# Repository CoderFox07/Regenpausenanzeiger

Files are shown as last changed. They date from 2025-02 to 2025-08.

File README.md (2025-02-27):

# Regenpausenanzeiger – Die etwas andere Wetterstation 🌦️

Der Regenpausenanzeiger ist ein modulares System zur Erfassung, Verarbeitung und Visualisierung von Wetterdaten. Drei vernetzte Stationen arbeiten dabei zusammen: Eine solarbetriebene Messstation auf dem Dach erfasst Temperatur, Luftfeuchtigkeit und Niederschlag. Eine Kontrollstation im Sekretariat verarbeitet die Daten und eine Anzeigestation macht die Wetterdaten für alle Schüler und Lehrkräfte zugänglich.

An vielen Schulen müssen die Schüler die Pausen grundsätzlich im Freien verbringen. Bei Regen oder sehr niedrigen Temperaturen dürfen sie jedoch im Gebäude bleiben. Dies ist dann eine Regen- oder Kältepause. Oft ist die Einschätzung der Wetterlage nicht ganz eindeutig oder die Durchsage, dass die Pause drinnen verbracht werden darf, wird vergessen.

Der Regenpausenanzeiger automatisiert diese Entscheidung – ist aber weit mehr als nur ein Pausenhelfer. Die erfassten Wetterdaten lassen sich vielfältig nutzen, etwa für den Unterricht oder als langfristige Wetterbeobachtungen. Er lässt sich ebenfalls leicht als Wetterstation für zu Hause umfunktionieren.

In diesem Repository befinden sich die Programme für die Stationen, 3D-Modelle und eine detaillierte Anleitung zur Einrichtung der Anzeigestation.

YouTube-Video für weitere spannende Details: [Video Regenpausenanzeiger](https://youtu.be/XeapUQ0t9Z4)

Ein ausführlicher Artikel zum Regenpausenanzeiger wurde von mir im AATiS-Praxisheft veröffentlicht: AATiS-Praxisheft 35 (2025), S. 36.
Homepage zum AATiS e.V., auf der man das Heft bestellen kann: [AATiS e.V.](https://www.aatis.de/)

Hier sind Links zu einigen der benötigten Komponenten:

-   **Solarpanel (5W):** [Waveshare Solarpanel 5 W](https://www.reichelt.de/de/de/shop/produkt/entwicklerboards_-_solarpanel_5_w-266039) (Reichelt)
-   **Solar Laderegler:** [Waveshare Solar Power Manager](https://www.reichelt.de/de/de/shop/produkt/entwicklerboards_-_solar_ladegeraet_fuer_6_bis_24_v_panels-266038) (Reichelt)
-   **Li-Ion Akku (14500, 750mAh):** [14500 Li-Ion-Akku 750 mAh mit Schutzschaltung](https://www.reichelt.de/de/de/shop/produkt/led_lenser_li-ion_14500_750_mah_mit_schutzschaltung-302260) (Reichelt)
-   **Trichter (20cm Durchmesser):** [Trichter 20cm Durchmesser](https://www.amazon.de/dp/B000VD6UXC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) (Amazon)

**Haftungsausschluss:**

Der Nachbau und die Verwendung dieses Projekts erfolgen auf eigene Gefahr. Der Autor übernimmt keine Haftung für Schäden, die durch den Nachbau oder die Verwendung entstehen.

**Disclaimer:**

The construction and use of this project are at your own risk. The author assumes no liability for any damage caused by the construction or use.

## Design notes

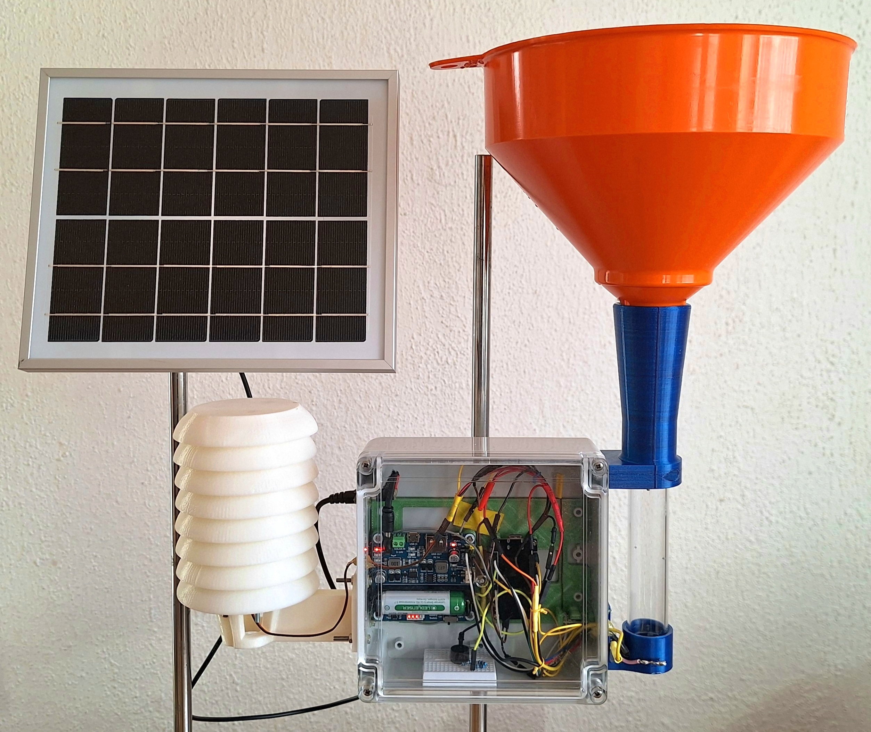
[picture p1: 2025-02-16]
Bilder/Dachstation.jpg

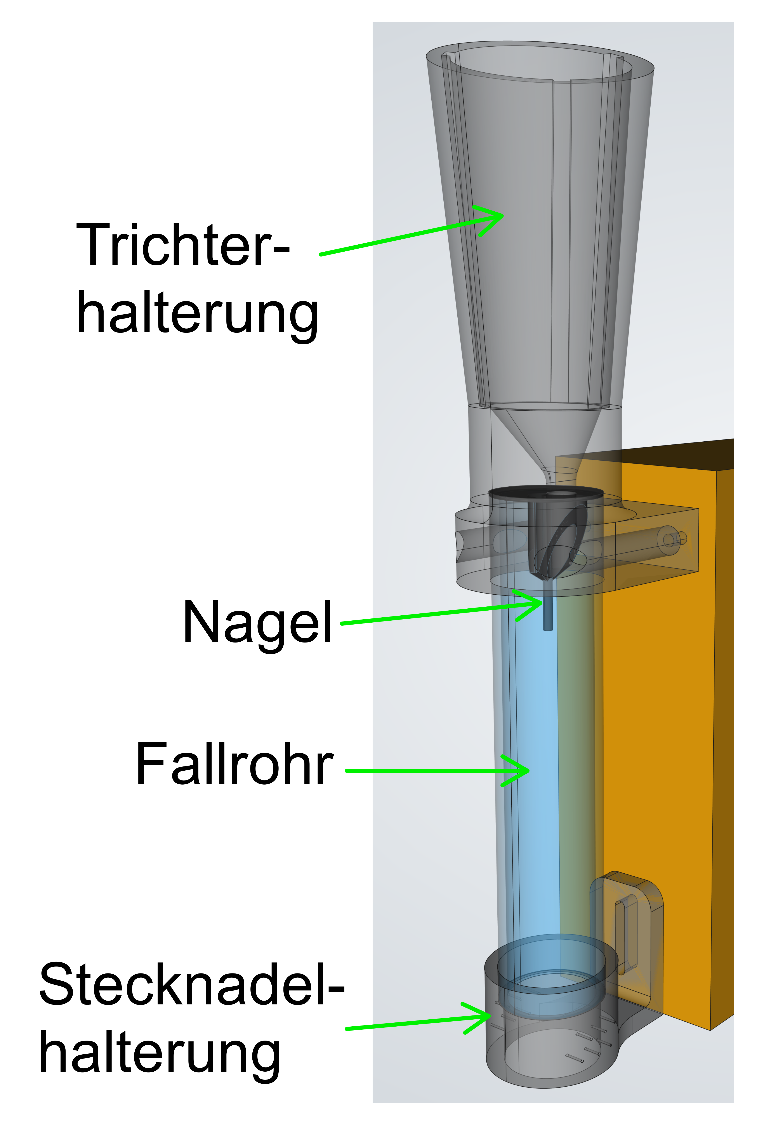
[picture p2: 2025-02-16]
Bilder/Beschriftungen Regensensor.png

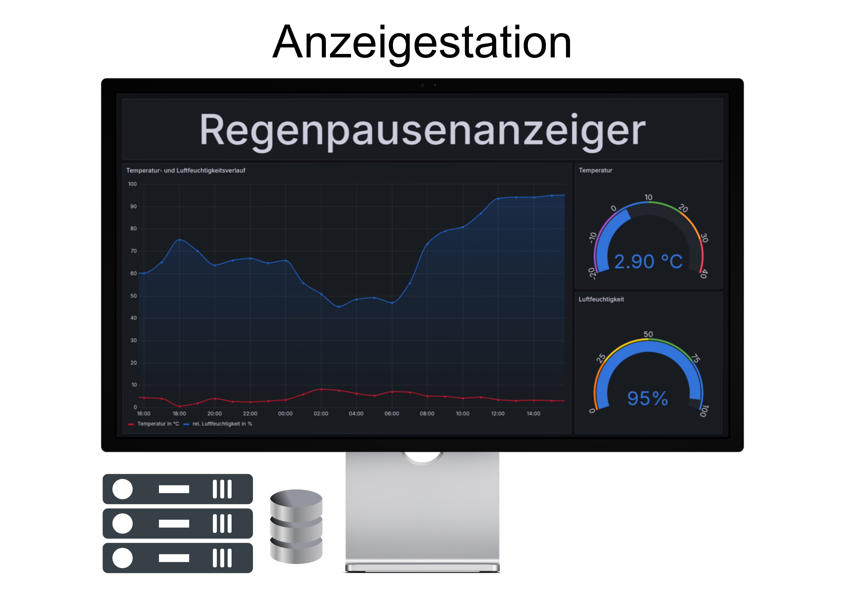
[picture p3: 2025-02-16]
Bilder/Anzeigestation.png

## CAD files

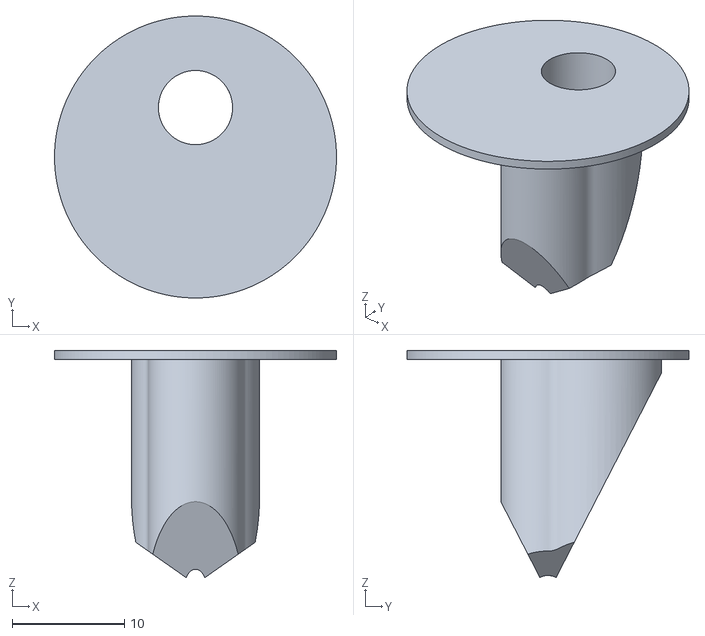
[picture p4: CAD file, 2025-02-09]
3D-Modelle/Regensensor/Regensensor V2-Wasserableiter.stl
25.1 x 25.1 x 20.2

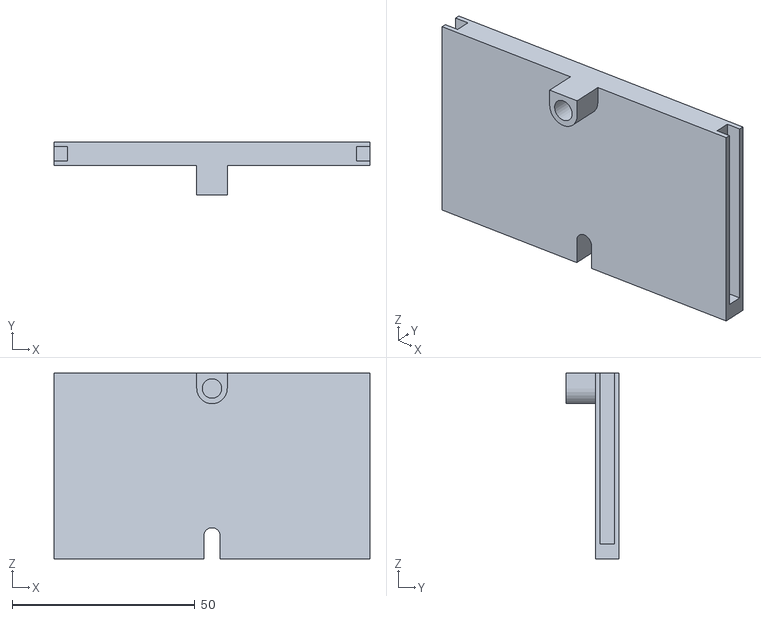
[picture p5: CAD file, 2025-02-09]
3D-Modelle/Sekretariatsstation/Sekretariatsstation-Einschiebedeckel.stl
86.5 x 14.6 x 50.8

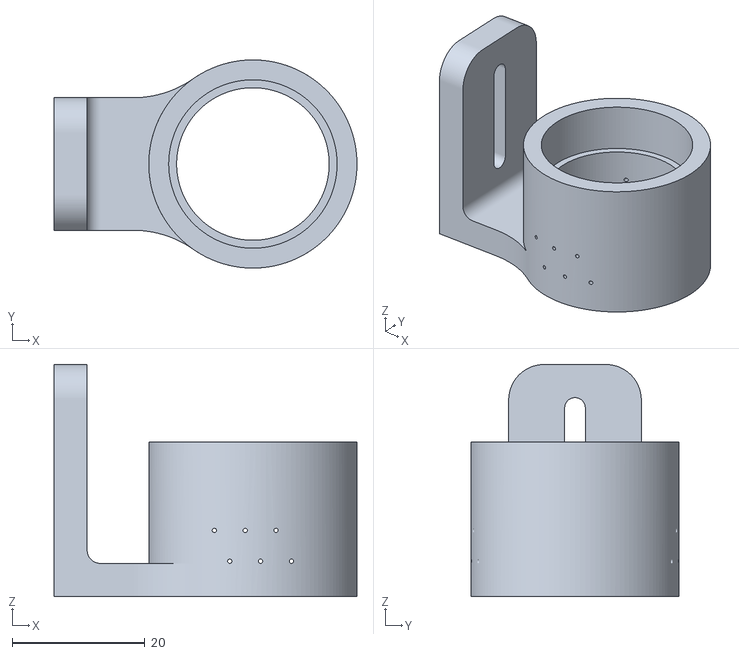
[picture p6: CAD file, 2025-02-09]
3D-Modelle/Regensensor/Regensensor V2-Stecknadelhalterung.stl
45.7 x 31.4 x 35.0

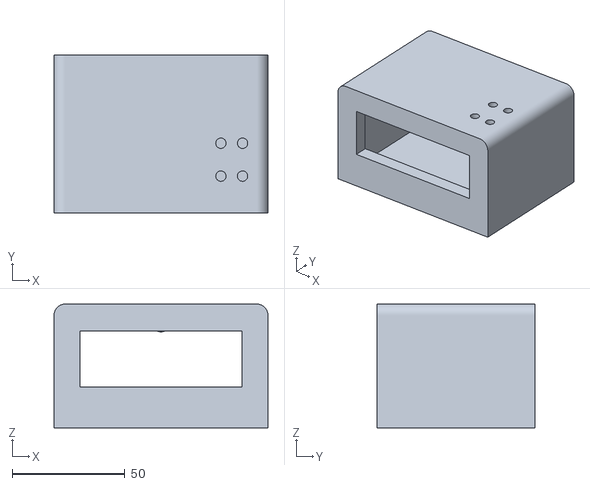
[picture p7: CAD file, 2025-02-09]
3D-Modelle/Sekretariatsstation/Sekretariatsstation-Box.stl
95.0 x 70.0 x 55.0

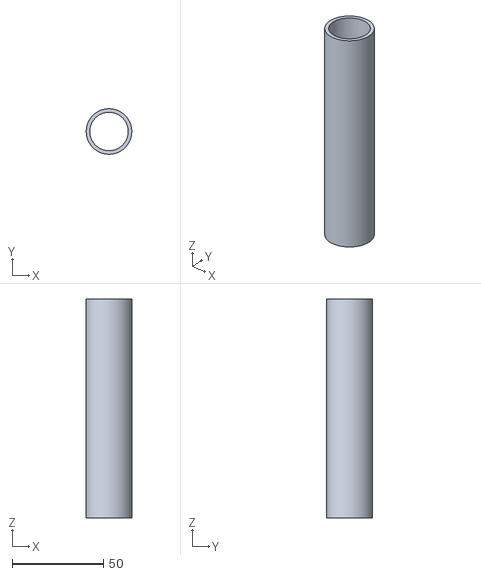
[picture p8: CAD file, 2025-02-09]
3D-Modelle/Regensensor/Regensensor V2-Rohr.stl
25.0 x 25.0 x 120.0

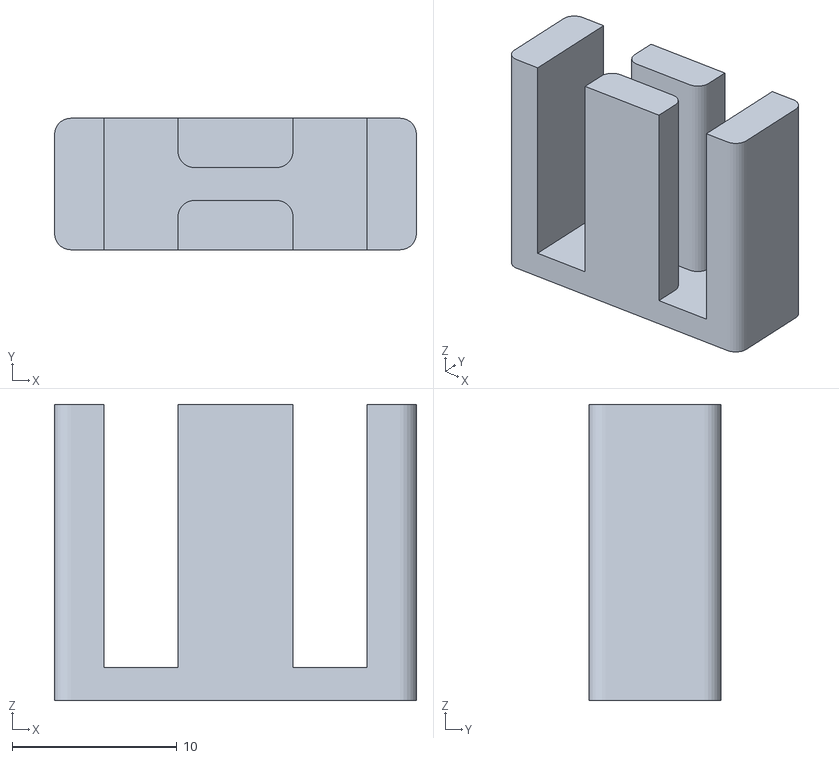
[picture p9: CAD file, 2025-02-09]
3D-Modelle/Sekretariatsstation/Sekretariatsstation-LoRa-Halterung.stl
22.0 x 8.00 x 18.0

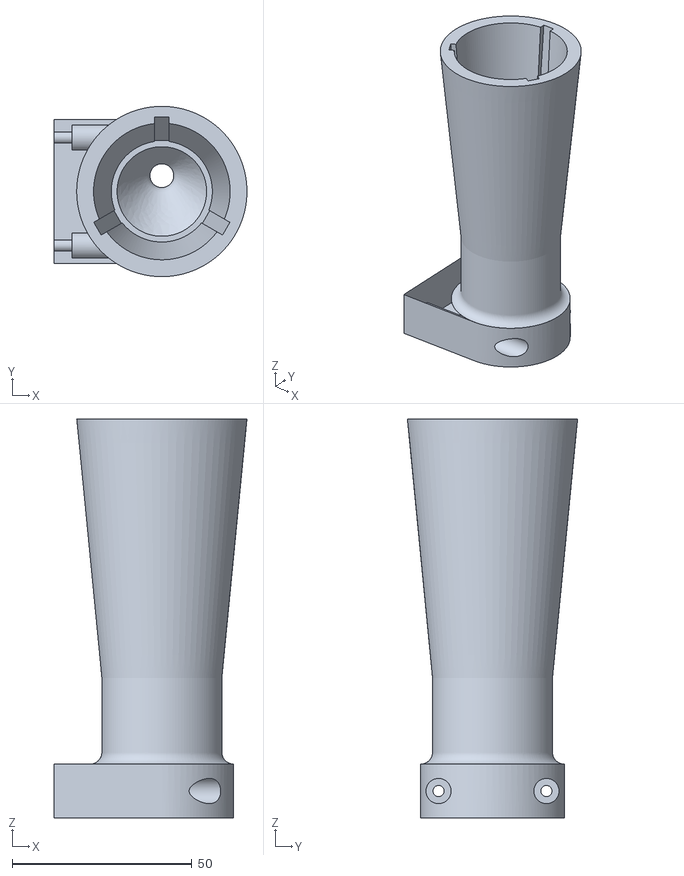
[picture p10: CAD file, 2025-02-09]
3D-Modelle/Regensensor/Regensensor V2-Trichterhalterung.stl
53.7 x 47.4 x 111.0

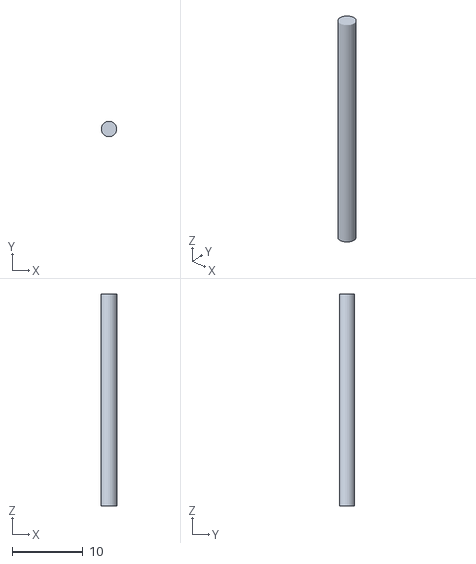
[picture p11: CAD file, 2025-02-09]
3D-Modelle/Regensensor/Regensensor V2-Nagel.stl
2.20 x 2.18 x 30.0

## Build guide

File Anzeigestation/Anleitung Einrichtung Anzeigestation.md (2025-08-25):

# Einrichtung der Anzeigestation des Regenpausenanzeigers

Diese Anleitung beschreibt die Installation und Konfiguration der Anzeigestation des Regenpausenanzeigers. Sie umfasst die Einrichtung eines LAMP-Servers (Linux, Apache, MariaDB, PHP), die Installation von phpMyAdmin und Grafana, sowie die Konfiguration für den automatischen Start und die Anzeige der Wetterdaten.
Dazu wird ein Computer mit Debian als Betriebssystem mit XFCE als Oberfläche vorrausgesetzt.

**Hinweis**: Diese Anleitung wurde mit Debian 12 und XFCE 4.18 getestet und sollte auch mit zukünftigen Debian-Versionen kompatibel sein. Bei einem Systemupgrade auf eine neue Debian-Hauptversion wird empfohlen, externe Paketquellen wie die von Grafana vorübergehend zu deaktivieren. Dabei muss Grafana nicht deinstalliert werden und Konfigurationen der Dashboards bleiben erhalten. Nach dem Upgrade müssen die Quellen wieder aktiviert werden, woraufhin Grafana über den Paketmanager normal aktualisiert werden kann.

## 1. Installation der Basispakete

Nach dem ersten Start des Systems installiere die folgenden Pakete:

```bash
sudo apt install htop net-tools
```

## 2. Optionale Zwei-Faktor-Authentifizierung (2FA) einrichten

Für Benutzer kann zusätzlich eine 2FA für erhöhte Sicherheit eingerichtet werden.
Dazu muss folgendes Paket installiert werden: libpam-google-authenticator
```bash
sudo apt install libpam-google-authenticator
```

Danach als normaler Benutzer einrichten:
```bash
google-authenticator
```
Anschließend müssen weitere Einstellungen vorgenommen werden.
Öffne dazu die Datei `/etc/pam.d/common-auth`:
```bash
sudo nano /etc/pam.d/common-auth
```
Sie sollte wie folgt angepasst werden:
```
#
# /etc/pam.d/common-auth - authentication settings common to all services
#
# This file is included from other service-specific PAM config files,
# and should contain a list of the authentication modules that define
# the central authentication scheme for use on the system
# (e.g., /etc/shadow, LDAP, Kerberos, etc.).  The default is to use the
# traditional Unix authentication mechanisms.
#
# As of pam 1.0.1-6, this file is managed by pam-auth-update by default.
# To take advantage of this, it is recommended that you configure any
# local modules either before or after the default block, and use
# pam-auth-update to manage selection of other modules.  See
# pam-auth-update(8) for details.

# here are the per-package modules (the "Primary" block)
# Hinweis: forward_pass sorgt dafür, dass man den Verification-Code direkt hinter das Passwort schreiben kann.
auth    required                        pam_google_authenticator.so forward_pass
auth	[success=1 default=ignore]	pam_unix.so nullok
# here's the fallback if no module succeeds
auth	requisite			pam_deny.so
# prime the stack with a positive return value if there isn't one already;
# this avoids us returning an error just because nothing sets a success code
# since the modules above will each just jump around
auth	required			pam_permit.so
# and here are more per-package modules (the "Additional" block)
# end of pam-auth-update config
```

## 3. VNC-Einrichtung

Installiere die notwendigen Pakete:
```bash
sudo apt install tigervnc-standalone-server tigervnc-common tigervnc-tools tigervnc-xorg-extension
```

### 3.1. VNC für neue Session

1.  **Anpassung des `xstartup`-Skripts:**
    Öffne die Datei `~/.vnc/xstartup`:
    ```bash
    nano ~/.vnc/xstartup
    ```

    Stelle sicher, dass der Inhalt wie folgt aussieht (ggf. anpassen):
    ```bash
    #!/bin/bash
    unset SESSION_MANAGER
    unset DBUS_SESSION_BUS_ADDRESS
    exec /usr/bin/startxfce4
    ```

    Mache das Skript ausführbar:
    ```bash
    chmod +x ~/.vnc/xstartup
    ```

2.  **VNC-Passwort festlegen (für den Benutzer, nicht root!):**
    ```bash
    vncpasswd
    ```

### 3.2 VNC für Shared Session (aktuellen Desktop teilen und fernsteuern)

1. Konfiguration:
Erstelle oder bearbeite die Datei /etc/X11/xorg.conf.d/10-tigervnc.conf:
```bash
sudo nano /etc/X11/xorg.conf.d/10-tigervnc.conf
```

Füge Folgendes ein:
```
Section "Module"
    Load "vnc"
EndSection

Section "Screen"
    Identifier "Screen0"
    Option "passwordFile" "/etc/vncpasswd"
    Option "localhost" "yes" #sorgt dafuer, dass es nicht von aussen erreichbar ist
EndSection
```

2. Systemweites VNC-Passwort setzen:
```bash
sudo vncpasswd /etc/vncpasswd
sudo chmod 600 /etc/vncpasswd
```

3. Neustart
```bash
sudo reboot
```

### 3.3 VNC-Zugriff auf Regenpausenanzeiger über SSH-Tunnel für verschlüsselte Übertragung

**Shared Session (Bildschirm teilen):**

1.  **SSH-Tunnel auf dem *lokalen* Rechner erstellen:**
    ```bash
    ssh -L 5900:localhost:5900 user@regenpausenanzeiger
    ```

2.  **Mit VNC-Viewer verbinden:**
    Verwende einen VNC-Viewer auf dem lokalen Rechner (z.B. TigerVNC Viewer) und verbinde dich mit `localhost:5900`.

**Neue Session:**

1.  **VNC-Server auf dem *Regenpausenanzeiger* starten:**
    Dazu muss man sich zunächst über ssh einloggen und den folgenden Befehl ausführen:
    ```bash
    tigervncserver :1 -geometry 1920x1080 -localhost -xstartup ~/.vnc/xstartup
    ```

2.  **SSH-Tunnel auf dem *lokalen* Rechner erstellen:**
    ```bash
    ssh -L 5901:localhost:5901 user@regenpausenanzeiger
    ```

3.  **Mit VNC-Viewer verbinden:**
    Verwende einen VNC-Viewer auf dem lokalen Rechner (z.B. TigerVNC Viewer) und verbinde dich mit `localhost:5901`.

## 4. LAMP-Server einrichten

### 4.1 MariaDB installieren

```bash
sudo apt install mariadb-server
```

### 4.2 MySQL/MariaDB absichern

Führe das Skript zur Absicherung aus:

```bash
sudo mysql_secure_installation
```

Beantworte die Fragen wie folgt (wähle sichere Passwörter!):

*   Enter current password for root (enter for none): **(Enter drücken, falls kein Passwort gesetzt)**
*   Switch to unix\_socket authentication \[Y/n] **Y**
*   Change the root password? \[Y/n] **Y**
*   Remove anonymous users? \[Y/n] **Y**
*   Disallow root login remotely? \[Y/n] **Y**
*   Remove test database and access to it? \[Y/n] **Y**
*   Reload privilege tables now? \[Y/n] **Y**

### 4.3 PHP und Erweiterungen installieren

```bash
sudo apt install php php-mysql libapache2-mod-php php-cli
```

### 4.4 Apache neu starten

```bash
sudo systemctl restart apache2
```

### 4.5 Datenbank und Benutzer erstellen

1.  **Mit der MariaDB-Konsole verbinden:**
    ```bash
    sudo mysql -u root -p
    ```

2.  **Datenbank erstellen:**
    ```sql
    CREATE DATABASE wetterdaten;
    ```

3.  **Hauptbenutzer erstellen und Rechte vergeben (ersetze 'sicheres_passwort'!):**
    ```sql
    CREATE USER 'wetteruser'@'localhost' IDENTIFIED BY 'sicheres_passwort';
    GRANT ALL PRIVILEGES ON wetterdaten.* TO 'wetteruser'@'localhost';
    FLUSH PRIVILEGES;
    ```

4.  **Benutzer für Grafana (nur Lesezugriff) erstellen (ersetze 'sicheresPasswort2'!):**
    ```sql
    CREATE USER 'grafanauser'@'localhost' IDENTIFIED BY 'sicheresPasswort2';
    GRANT SELECT ON wetterdaten.* TO 'grafanauser'@'localhost';
    FLUSH PRIVILEGES;
    EXIT;
    ```

### 4.6 Tabelle für Wetterdaten erstellen
```bash
sudo mysql -u wetteruser -p wetterdaten
```

### 4.7 phpMyAdmin installieren
```bash
sudo apt install phpmyadmin
```

Bearbeite die Datei /etc/phpmyadmin/apache.conf, um den Zugriff nur vom lokalen Server zu erlauben:
```bash
sudo nano /etc/phpmyadmin/apache.conf
```

Für mehr Sicherheit kann der Zugriff auf phpMyAdmin von außen beschränkt werden, indem man nur lokalen Zugriff gewährt. Um trotzdem noch von anderen Computern darauf zugreifen zu können, kann man sich über einen SSH-Tunnel sicher verbinden und den Port weiterleiten.

Füge dazu folgende Zeilen hinzu, um den Zugriff nur von localhost zu erlauben:
```
<IfModule mod_authz_core.c>
    # Restrict access to localhost
    Require local
</IfModule>
```

Die komplette Datei (etc/phpmyadmin/apache.conf) sollte folgendermaßen aussehen:
```
# phpMyAdmin default Apache configuration

Alias /phpmyadmin /usr/share/phpmyadmin

<Directory /usr/share/phpmyadmin>
    Options SymLinksIfOwnerMatch
    DirectoryIndex index.php

    # limit libapache2-mod-php to files and directories necessary by pma
    <IfModule mod_php7.c>
        php_admin_value upload_tmp_dir /var/lib/phpmyadmin/tmp
        php_admin_value open_basedir /usr/share/phpmyadmin/:/usr/share/doc/phpmyadmin/:/etc/phpmyadmin/:/var/lib/phpmyadmin/:/usr/share/php/:/usr/share/javascript/
    </IfModule>

    # PHP 8+
    <IfModule mod_php.c>
        php_admin_value upload_tmp_dir /var/lib/phpmyadmin/tmp
        php_admin_value open_basedir /usr/share/phpmyadmin/:/usr/share/doc/phpmyadmin/:/etc/phpmyadmin/:/var/lib/phpmyadmin/:/usr/share/php/:/usr/share/javascript/
    </IfModule>

    # Zugriff auf localhost beschraenken:
    <IfModule mod_authz_core.c>
        # Restrict access to localhost
        Require local
    </IfModule>
</Directory>

# Disallow web access to directories that don't need it
<Directory /usr/share/phpmyadmin/templates>
    Require all denied
</Directory>
<Directory /usr/share/phpmyadmin/libraries>
    Require all denied
</Directory>
```

Anschließend muss Apache neu gestartet werden, sodass die Änderungen wirksam werden:
```bash
sudo systemctl restart apache2
```
Jetzt ist phpMyAdmin nicht mehr von außen erreichbar. Man kann entweder mit <http://localhost:8888/phpmyadmin/index.php> im Browserfenster vom Regenpausenanzeiger auf phpMyAdmin zugreifen oder mit einem SSH-Tunnel, indem man folgendes an einem anderen Rechner lokalen Rechner eingibt:

```bash
ssh -L 8888:localhost:80 user@regenpausenanzeiger
```

Dann kann man am lokalen Rechner folgendes im Browser eingeben, um auf phpMyAdmin zuzugreifen:
```
http://localhost:8888/phpmyadmin
```

Anschließend kann man mit phpMyAdmin die SQL-Datenbank genauer konfigurieren, wie im Bild gezeigt:
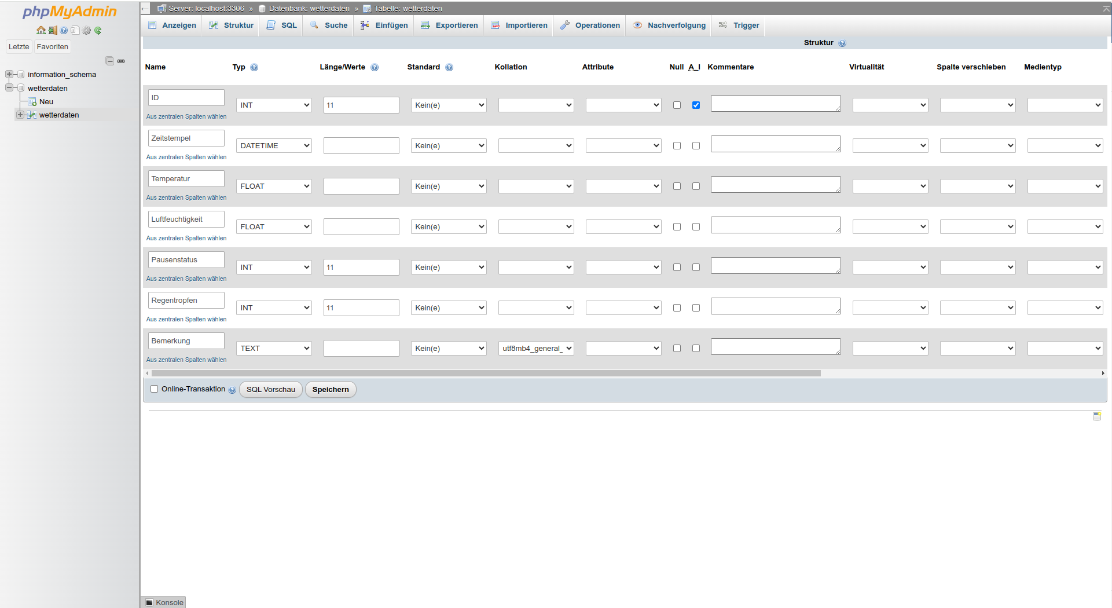
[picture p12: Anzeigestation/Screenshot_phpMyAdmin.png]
Screenshot Einrichtung SQL-Datenbank mit phpMyAdmin


Es werden insgesamt sieben Spalten benötigt:
1.  **ID:**
    Eine ID, die automatisch hochgezählt wird

2.  **Zeitstempel:**
    Für die Speicherung der Zeit: Wann die Wetterdaten von der Dachstation erfasst wurden.

3.  **Temperatur**

4.  **Luftfeuchtigkeit**

5.  **Pausenstatus:**
    Der Pausenstatus wird jedes Mal von der Sekretariatsstation mit übermittelt. Damit kann dann im Grafana-Dashboard entschieden werden, welcher Pausenmodus angezeigt werden soll. Im [Beispiel-Dashboard](Grafana/Wetterdaten.json) wird damit die Überschrift "Regenpausenanzeiger" während einer Pause entsprechend geändert.

6.  **Regentropfen:**
    Anzahl der Regentropfen

7.  **Bemerkung:**
    In dieser Zeile kann man evtl. mit phpMyAdmin manuell eine Bemerkung hinzufügen. Diese wird von der Sekretariatsstation nicht beeinflusst.

### 4.8 PHP-Skript zum Empfangen der Wetterdaten erstellen

Die Wetterdaten werden mithilfe eines PHP-Skripts in die Datenbank eingetragen.
Erstelle dafür die Datei `/var/www/html/rcvwetterdaten.php`:

```bash
sudo nano /var/www/html/rcvwetterdaten.php
```

Füge den folgenden Code ein (und **ersetze `'sicheres Passwort'` durch das tatsächliche Passwort des `wetteruser`!**):

```php
<?php
/*
// PHP-Fehler anzeigen für Debugging
ini_set('display_errors', 1);
ini_set('display_startup_errors', 1);
error_reporting(E_ALL);
*/

// Verbindungsparameter für die SQL-Datenbank
$servername = "localhost";
$username = "wetteruser";
$password = "sicheres Passwort"; // Falls Anfuehrungszeichen im Passwort enthalten sind, kann man ein Backslash vor das Zeichen setzen. Ein Backslash selbst muss mit einem Backslash escaped werden.
$dbname = "wetterdaten";
$datenGespeichert = "Daten erfolgreich gespeichert.";

// Verbindung zur Datenbank herstellen
$conn = new mysqli($servername, $username, $password, $dbname);

// Verbindung überprüfen
if ($conn->connect_error) {
    die("Verbindung zur Datenbank fehlgeschlagen: " . $conn->connect_error);
}

// Überprüfen des Hostnamens anhand der IP-Adresse des ESP32, dass nicht jeder einfach Wetterdaten im Netzwerk an die Anzeigestation senden kann und sie in die Datenbank eingetragen weden
$hostname = 'RPAsekretariat.local';  // Hostname der Sekretariatstation
$client_ip = $_SERVER['REMOTE_ADDR'];
$hostname_ip = gethostbyname($hostname);

// Überprüfen, ob die Anfrage von Sekretariatstation kommt
if ($client_ip === $hostname_ip) {

    // Überprüfen, ob Daten übergeben wurden
    if ($_SERVER["REQUEST_METHOD"] == "GET" && isset($_GET['datum']) && isset($_GET['uhrzeit']) && isset($_GET['temperatur']) && isset($_GET['luftfeuchtigkeit']) && isset($_GET['pausenstatus']) && isset($_GET['regentropfen'])) {

        // GET Daten entgegennehmen
        $datum = $_GET["datum"];
        $uhrzeit = $_GET["uhrzeit"];
        $temperatur = $_GET["temperatur"];
        $luftfeuchtigkeit = $_GET["luftfeuchtigkeit"];
        $pausenstatus = $_GET["pausenstatus"];
        $regentropfen = $_GET["regentropfen"];
        $bemerkung = isset($_GET["bemerkung"]) ? $_GET["bemerkung"] : '';

        // Datum und Uhrzeit zu einem DATETIME-Format zusammenführen
        $datetime_obj = DateTime::createFromFormat('Y-m-d H:i:s', "$datum $uhrzeit");
        if ($datetime_obj) {
            $datetime = $datetime_obj->format('Y-m-d H:i:s');

            // SQL-Statement vorbereiten
            $sql = "INSERT INTO wetterdaten (zeitstempel, temperatur, luftfeuchtigkeit, pausenstatus, regentropfen, bemerkung)
                    VALUES ('$datetime', '$temperatur', '$luftfeuchtigkeit', '$pausenstatus', '$regentropfen', '$bemerkung')";

            if ($conn->query($sql) === TRUE) {
                echo $datenGespeichert;
            } else {
                echo "Fehler beim Speichern der Daten: " . $conn->error;
            }
        } else {
            echo "Ungültiges Datum oder Uhrzeit!";
        }
    } else {
        echo "Daten nicht im richtigen Format gesendet!!!";
    }
} else {
    // Wenn der Hostname nicht übereinstimmt, Fehlermeldung ausgeben
    echo "Zugriff verweigert.";
}

// Verbindung schließen
$conn->close();
?>
```

Setze die korrekten Berechtigungen und starte Apache neu:

```bash
sudo chown www-data:www-data /var/www/html/rcvwetterdaten.php
sudo chmod 640 /var/www/html/rcvwetterdaten.php
sudo systemctl restart apache2
```

## 5. Grafana installieren und konfigurieren
Für die Visualisierung der Wetterdaten wird [Grafana](https://grafana.com/) verwendet. Um das Grafana-Dashboard anzuzeigen wird Firefox benötigt. Das sollte bereits vorinstalliert sein.

**Installation von Grafana:**
Eine genaue Anleitung zur Installation von Grafana befindet sich [hier](https://grafana.com/docs/grafana/latest/setup-grafana/installation/debian/).

1.  **Voraussetzungen installieren:**
    ```bash
    sudo apt install apt-transport-https software-properties-common wget
    ```

2.  **GPG-Schlüssel importieren:**
    ```bash
    sudo mkdir -p /etc/apt/keyrings/
    wget -q -O - https://apt.grafana.com/gpg.key | gpg --dearmor | sudo tee /etc/apt/keyrings/grafana.gpg > /dev/null
    ```

3.  **Repository hinzufügen (für stabile Versionen):**
    ```bash
    echo "deb [signed-by=/etc/apt/keyrings/grafana.gpg] https://apt.grafana.com stable main" | sudo tee -a /etc/apt/sources.list.d/grafana.list
    ```

4.  **Paketlisten aktualisieren:**
    ```bash
    sudo apt update
    ```

5.  **Grafana installieren:**
    ```bash
    sudo apt install grafana
    ```

**Grafana konfigurieren:**

*   **Anonymen Zugriff auf Dashboards aktivieren:**
    Wenn das Wetterdashboard für jeden im Netzwerk ohne Anmeldung verfügbar sein soll, muss man dies explizit erlauben:
    ```bash
    sudo nano /etc/grafana/grafana.ini
    ```

    Suche den Abschnitt `[auth.anonymous]` und ändere die Zeile `;enabled = false` wie folgt:
    ```ini
    enabled = true
    ```

*   **Grafana beim Systemstart starten:**
    ```bash
    sudo systemctl enable grafana-server.service
    ```
    (Zum Neustarten: `sudo systemctl restart grafana-server`)

*   **Erstanmeldung bei Grafana:**
    *   Öffne im Browser: `http://localhost:3000`
    *   Standard-Login: Benutzername `admin`, Passwort `admin`.
    *   *   Du wirst aufgefordert, das Passwort zu ändern.

Um Einstellungen in Grafana sicher vorzunehmen (da nur http verwendet wird), kann der Port von Grafana per SSH-Tunnel weitergeleitet werden:
```bash
ssh -L 3000:localhost:3000 user@regenpausenanzeiger
```
Dann kann man lokal im Browser mittels <http://localhost:3000/> auf Grafana zugreifen.

**Grafana-Dashboard erstellen:**

Eine detaillierte Anleitung zur Erstellung von Grafana-Dashboards findest du in der offiziellen Grafana-Dokumentation:

*   [Dashboards](https://grafana.com/docs/grafana/latest/dashboards/)
*   [Panels und Visualisierungen](https://grafana.com/docs/grafana/latest/panels-visualizations/)

Schritte für die Erstellung eines Dashboards:
1.  Melde dich bei Grafana an.
2.  Klicke auf das  Plus-Symbol ("+", oben rechts) und wähle "Neues Dashboard".
3.  Klicke dann auf den Button "Visualisierung hinzufügen"
4.  Danach muss eine Datenquelle hinzufügt weden. In diesem Fall: MySQL
5.  Gib die Verbindungsdaten für die Datenquelle an:
    *   **Host URL:**  `localhost:3306`
    *   **Database name:** `wetterdaten`
    *   **Database:** `wetterdaten`
    *   **Username (haben wir vorher angelegt):** `grafanauser`
    *   **Password:**  Das Passwort des `grafanauser`.
6.  Klicke auf "Save & Test". Eine Erfolgsmeldung sollte erscheinen.

Anschließend kann man sein eigenes Dashboard erstellen. Es können ebenfalls Dashboards importiert werden. Ein Beispiel-Dashboard für den Regenpausenanzeiger befindet [hier](Grafana/Wetterdaten.json).
Dieses Beispiel-Dashboard zeigt die aktuellen Wetterdaten, sowie den Verlauf der letzten 24 Stunden an. Wenn gerade eine Pause ist, dann ändert sich die Überschrift "Regenpausenanzeiger" zur entsprechenden Pause.

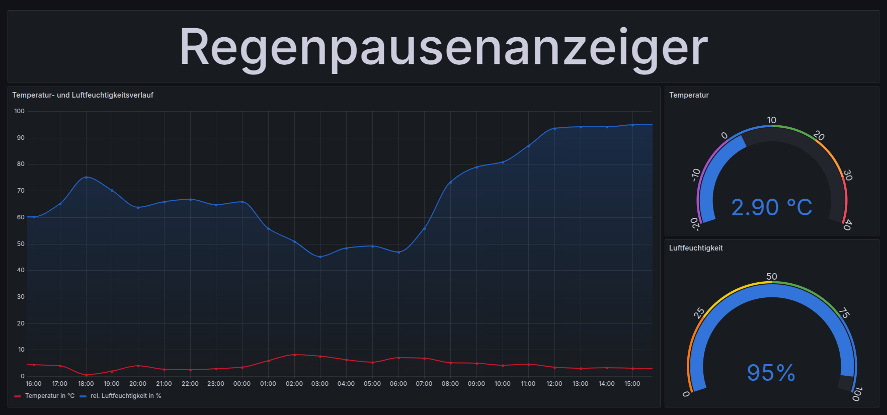
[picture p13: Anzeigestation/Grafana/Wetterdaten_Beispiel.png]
Screenshot Grafana-Dashboard


## 6. Zugriff über `regenpausenanzeiger.local` im lokalen Netzwerk

Um das Grafana-Dashboard im lokalen Netzwerk unter dem Namen `regenpausenanzeiger.local` verfügbar zu machen, wird eine eine Weiterleitung erstellt:

1.  **Alte `index.html` umbenennen:**
    ```bash
    cd /var/www/html/
    sudo mv index.html old_index.html
    ```

2.  **Neue `index.html` mit Weiterleitung erstellen:**
    ```bash
    sudo nano /var/www/html/index.html
    ```

    Füge folgenden Inhalt ein (passe die URL ggf. an, wenn du ein anderes Dashboard oder einen anderen Port verwendest):
    ```html
    <!DOCTYPE html PUBLIC "-//W3C//DTD XHTML 1.0 Transitional//EN" "http://www.w3.org/TR/xhtml1/DTD/xhtml1-transitional.dtd">
    <html xmlns="http://www.w3.org/1999/xhtml">
      <head>
        <meta http-equiv="Content-Type" content="text/html; charset=UTF-8" />
        <meta http-equiv="refresh" content="0; url=http://regenpausenanzeiger.local:3000/d/adzzbfrw8vapsa/wetterdaten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" />
      </head>
    </html>
    ```
     * Erläuterung:
        *   `http-equiv="refresh" ...`: Leitet den Browser automatisch weiter.
        *   `url=...`: Die URL des Grafana-Dashboards.
            *   `regenpausenanzeiger.local`: Der Hostname der Anzeigestation.
            *   `:3000`: Der Standardport von Grafana.
            *   `/d/adzzbfrw8vapsa/wetterdaten`: Der eindeutige Bezeichner des Dashboards (kann in der URL des Dashboards im Dashboard-Editor gefunden werden).
            *   `?orgId=1`: Die Organisations-ID (normalerweise 1).
            *    `&from=now-24h&to=now`: Zeigt die Daten der letzten 24 Stunden an.
            *   `&refresh=1m`: Aktualisiert das Dashboard jede Minute.
            *   `&kiosk`: Startet das Dashboard im Kiosk-Modus (ohne Menüs).

## 7. Automatischer Login und Autostart
Damit das Grafana-Dashboard nach dem Einschalten automatisch angezeigt wird, muss ein Benutzer einrichtet werden, der sich ohne Passwort mit Autologin automatisch anmeldet und das Grafana-Dashboard in Firefox im Kioskmodus startet. 

### 7.1 Benutzer `wetterdisplay` erstellen

Erstelle einen Benutzer `wetterdisplay` und setze irgendein Passwort:
```bash
sudo adduser wetterdisplay
```

Passe /etc/pam.d/common-auth an:
```bash
sudo nano /etc/pam.d/common-auth
```

Füge folgende Zeile *vor* `auth    required     pam_google_authenticator.so forward_pass` ein:
```
auth    [success=3 default=ignore]      pam_succeed_if.so user = wetterdisplay
```

Die Datei sollte nun so aussehen:
```
#
# /etc/pam.d/common-auth - authentication settings common to all services
#
# This file is included from other service-specific PAM config files,
# and should contain a list of the authentication modules that define
# the central authentication scheme for use on the system
# (e.g., /etc/shadow, LDAP, Kerberos, etc.).  The default is to use the
# traditional Unix authentication mechanisms.
#
# As of pam 1.0.1-6, this file is managed by pam-auth-update by default.
# To take advantage of this, it is recommended that you configure any
# local modules either before or after the default block, and use
# pam-auth-update to manage selection of other modules.  See
# pam-auth-update(8) for details.

# here are the per-package modules (the "Primary" block)
# Benuter Wetterdisplay soll ohne Passwort und 2FA funktionieren
auth [success=3 default=ignore] pam_succeed_if.so user = wetterdisplay
# Hinweis: forward_pass sorgt dafür, dass man den Verification-Code direkt hinter das Passwort schreiben kann.
auth    required                        pam_google_authenticator.so forward_pass

auth	[success=1 default=ignore]	pam_unix.so nullok
# here's the fallback if no module succeeds
auth	requisite			pam_deny.so
# prime the stack with a positive return value if there isn't one already;
# this avoids us returning an error just because nothing sets a success code
# since the modules above will each just jump around
auth	required			pam_permit.so
# and here are more per-package modules (the "Additional" block)
# end of pam-auth-update config
```

### 7.2 `wetterdisplay` von SSH ausschließen
Der Benutzer `wetterdisplay` darf aus Sicherheitsgründen kein SSH benutzen!

Füge am Ende von `/etc/ssh/sshd_config` Folgendes hinzu:
```bash
sudo nano /etc/ssh/sshd_config
```
```
DenyUsers wetterdisplay
```

Starte SSH neu:
```bash
sudo systemctl restart ssh
```

### 7.3 Autologin konfigurieren

Bearbeite `/etc/lightdm/lightdm.conf`:
```bash
sudo nano /etc/lightdm/lightdm.conf
```

Finde den Abschnitt `[Seat:*]` und füge folgende Zeilen hinzu (oder ändere sie, falls sie existieren):
```
autologin-user=wetterdisplay
autologin-user-timeout=100
```
(100 Sekunden Timeout, damit man sich ggf. noch manuell mit einem anderen Benutzer anmelden kann.)

### 7.4 Autostart von Firefox im Kiosk-Modus

Den Autostart kann man grafisch in den Einstellungen einrichten:
*   Öffne die Einstellungen ("Sitzung und Startverhalten").
*   Gehe zum Reiter "Automatisch gestartete Anwendungen".
*   Klicke auf "Hinzufügen".
*   Gib einen Namen ein (z.B. "Firefox Grafana").
*   Gib als Befehl ein:
    ```
    firefox --kiosk localhost:3000/d/adzzbfrw8vapsa/wetterdaten?orgId=1&from=now-24h&to=now&refresh=1m&kiosk
    ```
    **Passe die URL an, falls nötig!!!**

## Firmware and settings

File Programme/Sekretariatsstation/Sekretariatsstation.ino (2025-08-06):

/*
Regenpausenanzeiger - Sekretariatsstation.ino
Copyright (C) 2025  Aurelio Dobmeier

Dieses Programm ist freie Software: Sie können es unter den Bedingungen
der GNU Affero General Public License, wie von der Free Software Foundation,
Version 3 der Lizenz oder (nach Ihrer Wahl) jeder späteren
veröffentlichten Version, weitergeben und/oder modifizieren.

Dieses Programm wird in der Hoffnung verteilt, dass es nützlich sein wird,
aber OHNE JEDE GEWÄHRLEISTUNG; auch ohne die implizite Gewährleistung der
MARKTGÄNGIGKEIT oder der EIGNUNG FÜR EINEN BESTIMMTEN ZWECK.
Weitere Einzelheiten finden Sie in der GNU Affero General Public License.

Sie sollten eine Kopie der GNU Affero General Public License zusammen mit
diesem Programm erhalten haben. Wenn nicht, siehe <https://www.gnu.org/licenses/>.

----

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
You should have received a copy of the GNU Affero General Public License
along with this program.  If not, see <https://www.gnu.org/licenses/>.
*/


// ==================== Variablen zur Konfiguration des Regenpausenanzeigers ====================
// ---------- WLAN-Zugangsdaten ----------
const char *ssid = "WLAN-Name";
const char *password = "WLAN-Passwort";

// ---------- Schwellen für Regen- und Kältepause ----------
const long regenschwelle = 20;  // Schwelle, ab wann eine Pause als Regenpause in der eingestellten Messzeit (-> dauerRegenmessung) gilt --> muss kalibriert werden (Bsp: 20 Tropfen in 10 min).
const float schwelleKaeltepause = 0.0;

// ---------- Intervall Wetterdaten, Dauer Regenmessung ----------
const int dauerSchlafenszeitDachstation = 10;                                // Gibt in min. an, in welchem Intervall die Dachstation aufwachen soll und die Wetterdaten schicken soll
const int dauerRegenmessung = 10;                                            // Wie lange die Regenstärke in Minuten gemessen werden soll
const int schwelleWarnmeldungDatenZuletztEmpfangenVonDach = 600000 + 60000;  // Schwelle, ab wann eine Warnung ausgegeben werden soll: nach dauerSchlafenszeitDachstation aber noch eine Minute Puffer: 10min + 1min

// ---------- Zeiten der Pausen und Messbeginn Regenmessung ----------
const byte anzahlPausen = 1;  // Für wie viele Pausen eine Regenmessung durchgeführt werden soll
                              // Wenn keine Regenmessungen durchgeführt werden sollen und damit auch keine Regenpausen, etc. angezeigt weden soll,
                              // dann 0 eintragen und die die Arrays für die Uhrzeiten der Pausen leer lassen

// In den folgenden beiden Arrays müssen die Pausenzeiten eingetragen werden.
// Im ersten müssen die Stunden eingetragen werden.
// Im zweiten die Minuten der Pause
// Die Stunden und Minuten müssen von links nach rechts eingetragen werden.
// Die jeweils untereinander stehenden Werte gehören zu einer Uhrzeit (-> Stunde und Minute)
// Bei mehreren Pausen müssen die einzelnen Werte durch Kommas "," getrennt werden.
const int pausenStunden[anzahlPausen] = { 11 };
const int pausenMinuten[anzahlPausen] = { 0 };

// Im fogenden Array kann eingetragen werden, an welchen Tagen eine Regenmessung gestartet wird.
// Von links nach rechts sind die Wochentage. Es beginnt mit Sonntag und endet mit Samstag.
// 0 steht für keine Regenmessungen am jeweiligen Tag; 1 steht für Regenmessungen am jeweiligen Tag
// Beispiel für "nur Regenmessungen unter der Woche und keine am Wochenende": { 0, 1, 1, 1, 1, 1, 0 }
const int messTage[7] = { 0, 1, 1, 1, 1, 1, 0 };

const int messbeginnVorPause = dauerRegenmessung + 3;  // Der Messbeginn der Regenmessung vor der Pause sein: So lange, wie die Messung dauert + z.B. 3 min. So steht das Ergebnis kurz vor der Pause fest.
int pufferBeginnRegenmessung = 3;                      // Pufferzeit in Minuten, in der die Regenmessung trotzdem nach eigentlichem Messbeginn noch gestartet wird (z.B. 3 min)

const long dauerLEDsAnNachRegenmessung = 1200000;    // Die LEDs sollen 20 min = 1200000 ms nach der eingehenden Regenmessung (also während der Pause) leuchten, bis sie aus gehen sollen.
                                                     // Die Anzeigestation hängt auch davon ab: Es wird dort auch solange Regenpause/Schoenwetterpause/... angezeigt.
const int dauerRegenpausenAenderungsTimer = 780000;  // Falls es einen Messfehler gab, kann man nach der Festlegung der Pause, innerhalb von der Zeit des Timers die Pause manuel zu
                                                     // Regen-/Schoenwetterpause ändern (Bsp: 13 min = 780000). Danach ist es nicht mehr möglich eine Änderung durchzuführen
const int drueckDauerPausenAendrerung = 3000;        // Drückdauer des Buttons, um den Pausenstatus zu ändern

// ---------- Anzeigedauer (Millisekunden) der einzelnen Schritte beim Starten ----------
const int anzeigedauerStartdetails = 250;

// ---------- Name des Servers und Pfad, wo die Wetterdaten durch das PHP-Skript gespeichert werden ----------
const String serverName = "http://regenpausenanzeiger.local/rcvwetterdaten.php?";  // Entweder IP-Adresse oder Hostname eigeben (IP nur wenn sie statisch ist!)

// ---------- Im PHP-Skript eingestellter Bestätigungstext, wenn die empfangenen Wetterdaten erfolgreich in SQL-Datenbank gespeichert wurden ----------
const String bestaetigungAnzeigestation = "Daten erfolgreich gespeichert.";  // Wird als Bestätigung benötigt, dass die Daten nochmals gesendet werden, wenn es einen Fehler gab.
// ++++++++++++++++++++ Variablen zur Konfiguration des Regenpausenanzeigers ++++++++++++++++++++


//==================== Bibliotheken ====================
// Die Bibliotheken müssen eventuell nachinstalliert werden!
//---------- LoRa ----------
#include <LoRa.h>
#include <SPI.h>

//---------- Wlan ----------
#include <WiFi.h>

//---------- Verbindung mit Vertretungsplanstation, Website ----------
#include <ESPmDNS.h>
#include <ESPAsyncWebServer.h>
#include <ESPAsyncHTTPClient.h>

//---------- OTA ----------
// Mittels OTA lassen sich Updates über die ferne durchführen.
// In diesem Fall über das lokale Netz. Dazu kann man in der Arduino IDE bei Ports den Netzwerkport von der Sekretariatsstation auswählen und den Code hochladen
// Das Passwort kann im setup() als MD5-Hash konfiguriert werden. So kann nicht jeder einfach Code hochladen.
#include <ArduinoOTA.h>

//---------- Zeit ----------
#include "time.h"

//---------- Display ----------
#include <Wire.h>
#include <LiquidCrystal_I2C.h>

//++++++++++++++++++++ Bibliotheken ++++++++++++++++++++


//==================== LoRa; Verbindung mit Dachstation ====================
// Pins für das LoRa-Modul (RFM95)
#define SS 5
#define RST 14
#define DIO0 2
// Einstellen der genauen Freuqenz. Ist abhängig von der Region und muss den entsprechenden Vorgaben eingestellt werden!!!
#define BAND 869.525E6  // Bsp. Frequenz in Hz für 869,525 MHz

bool Dachstation_STATUS = 0;                     //rote LED soll leuchten (0 = alles gut, 1 = Problem), wenn kein WLAN verbunden ist
unsigned long datenZuletztEmpfangenVonDach = 0;  //Timer, der speichert, wann zuletzt Daten von der Dachstation empfangen wurden
int dauerZuletztGesendeteSchlafenszeit = 0;

// Um die Wetterdaten über LoRa auszutauschen ist ein bestimmtes Format notwendig: Präfix Typ seperator1 Spannung seperator2 Temperatur seperator3 Luftfeucht. seperator4 (Regentropfen)
// Je nach dem, ob Regedaten übermittelt werden oder nicht, wird entweder "typTemp" oder "typRain" nach dem Präfix verwendet.
// Dass die Ziffern von Temp. und Luftfeucht. nicht direkt nebeneinander stehen, wird ein Seperator benötigt.
// Beispiel für eine LoRa-Nachricht: #RPAtempB3.53T12.30H78.90W oder #RPArainB3.2T13.20H79.80W56 (-> 13.2°C; 79.8% Luftfeucht.; 56 Topfen)
// WICHTIG: Es dürfen in der gesamten LoRa-Nachricht keine Buchstaben doppelt vorkommen, die als Seperator benutzt werden!!!
struct LoRaData {
  const String praefix = "#RPA";
  const String typTemp = "temp";
  const String typRain = "rain";
  const String seperator1 = "B";  // Akku/ Battery
  const String seperator2 = "T";  // Temperatur
  const String seperator3 = "H";  // Luftfeuchtigkeit / Humidity
  const String seperator4 = "W";  // Regentropfen / Wasser
  // Zur Steuerung der Dachstation:
  const String typSleep = "sleep";            // wird benutzt, um die Schlafenszeit/ DeepSleep-Zeit für die Dachstation zu übermitteln.
  const String seperatorSleep = "S";          // Beispiel: (loRaData.praefix + loRaData.typSleep + loRaData.seperatorSleep + dauerSchlafenszeitDachstation) -> RPAsleepS600000
  const String seperatorDauerRmessung = "D";  // außer sleep wird LoRaDatatypRain mit Dauer nach LoRaDataseperatorDauerRmessung benutzt, um eine Regenmessung anzufordern.

  // Variablen, um die Signalqualität für das empfangene Paket abzuspeichern:
  String empfangenesPaket = "";
  String uhrzeitUTCWetterEmpfagen = "";  // Wird später in UTC und nicht lokaler Zeit gespeichert!
  String datumUTCWetterEmpfagen = "";    // Wird später in UTC und nicht lokaler Zeit gespeichert!
  String rssiWetterdaten = "";
  String snrWetterdaten = "";
} loRaData;
//++++++++++++++++++++ LoRa; Verbindung mit Dachstation ++++++++++++++++++++


//==================== Wlan ====================
const char *hostname = "RPAsekretariat";  // Hostname der Sekretariatsstation

// Status: rote LED soll leuchten, wenn kein WLAN verbunden ist
bool WLAN_STATUS = 0;

const int reconnectIntervall = 3000;
unsigned long reconnectTimer = 0;  //Timer, mit dem alle paar Sekunden versucht wird, sich wieder mit dem WLAN zu verbinden, falls Verbindung fehlschlägt
//++++++++++++++++++++ Wlan ++++++++++++++++++++


//==================== Verbindung mit Anzeigestation ====================
AsyncHTTPClient http;
bool datenAnAnzeigeGesendet = true;  // Wird auf true gesetzt, wenn die neuesten Daten schon an Anzeigestation gesendet wurden (am Anfang, bis erste Daten kommen True, da nichts zum Senden)
bool httpAnfrageLaeuft = false;      // Wird während die http-Anfrage läuft auf true gesetzt

// Zu sendende Parameter in diesem Format:
// http://regenpausenanzeiger.local/rcvwetterdaten.php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
// Wichtig: Uhrzeit und Datum werden im UTC-Format gesendet!
String wetterdatenFuerAnzeige = "";  // Variable, die Wetterdaten in Form der restlichen http-Anfrage enthält

const int ablaufzeitHttpAnfrage = 10000;
unsigned long timerAblaufzeitHttpAnfrage = 0;
//++++++++++++++++++++ Verbindung mit Anzeigestation ++++++++++++++++++++


//==================== Website ====================
// Die Sekretariatsstation gibt beim aufrufen ihrer IP-Adresse oder Hostname eine Website aus, die der Wartung dient.
AsyncWebServer server(80);

// Variablen, in denen die einzelnen Teile der Website gespeichert werden. Die Website wird zur Vereinfachrung direkt im Code gespeichert. Falls der Speicher knapp wird, kann sie entfernt werden.
struct Website {
  const String Head = "<!DOCTYPE html><html><head><meta name =\"viewport\" content=\"width=device-width, initial-scale = 1\">";
  const String Style = "<style> html, body { font-family: Helvetica; margin: 0; height: 100%; display: flex; justify-content: top; align-items: center; flex-direction: column; } .container { text-align: left; padding: 10px; border: 0px solid #0f0f0f; border-radius: 20px; background-color:";
  String TempHum;
  String Pausenstatus;
  String DatenVon;
  String AnzahlTropfen;
  const String Ende = "</div></body></html>";
  String pausenStatus;

  // Hintergrundfarbe
  const String regenpausenFarbe = "#8888ff";
  const String keineRegenpausenFarbe = "#ffff88";
} website;
//++++++++++++++++++++ Website ++++++++++++++++++++


//==================== Zeit ====================
const String zeitzone = "CET-1CEST,M3.5.0/1,M10.5.0/3";  // Zeit für Berlin
// Variablen, in denen die Zeit abgespeichert wird:
struct Zeit {
  String Datum = "";
  String Uhrzeit = "";
  String DatumUTC = "";
  String UhrzeitUTC = "";
  int stunde, minute, sekunde, tag, monat, jahr, wochentag;
} zeit;
//++++++++++++++++++++ Zeit ++++++++++++++++++++


//==================== LC-Display ====================
LiquidCrystal_I2C LCD(0x27, 16, 2);
//++++++++++++++++++++ LC-Display ++++++++++++++++++++


//==================== Status-LEDs ====================
// Pins der Status-LEDs:
#define LED_Status_Gruen 32
#define LED_Status_Rot 33
#define LED_Regenpause 25
#define LED_KeineRegenpause 26

unsigned long timerPausenLEDsAus = 0;  // Timer (wird auf millis() gesetzt), der die LEDs (für Pausenstatus) nach oben konfigurierter Dauer wieder ausschalten lässt.
bool statusWetterLEDs = 0;             // 0 = aus; 1 = an; wird während der Laufzeit angepasst
//++++++++++++++++++++ Status-LEDs ++++++++++++++++++++

//==================== Button ====================
//(roter) Knopf/ Taster (seitlich an der Sekretariatsstation), um eine Pause manuell festzulegen, falls nötig (z.B. bei Messfehler)
#define ButtonPin 27

// Variablen für den Button
struct Button {
  bool status = 0;          // In diese Variable wird der ausgelesene Button-Status (gedrückt, oder nicht) gespeichert.
  bool zuvorGedrueckt = 0;  // Um die Zeit, die der Button gedrückt ist zu ermitteln, benötigt man eine Variable, in der der voherige Status des Buttons gespeichert wird.
  unsigned long timer = 0;  // Timer, um die Drück-Dauer des Buttons zu ermitteln (wird auf millis() gesetzt)
} button;

unsigned long regenpausenAenderungsTimer = 0;
//++++++++++++++++++++ Button ++++++++++++++++++++
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
void loop() {
  ArduinoOTA.handle();
  // Überprüfe, ob WLAN verbunden ist und verbinde erneut, falls nötig
  if ((WiFi.status() != WL_CONNECTED) && (millis() > (reconnectIntervall + reconnectTimer))) {
    Serial.println("WLAN nicht mehr verbunden!");
    WLAN_STATUS = 1;
    Serial.println("Reconnecting to WiFi...");
    WiFi.disconnect();
    WiFi.reconnect();
    reconnectTimer = millis();
  } else if (WiFi.status() == WL_CONNECTED) {
    WLAN_STATUS = 0;
  }


  button.status = digitalRead(ButtonPin);
  // Um den Pausenmodus zu ändern muss man den Button solange, wie oben konfiguriert (-> drueckDauerPausenAendrerung) drücken. Erst dann soll der Pausenmodus geändert weden.
  // Um den Code nicht zu blockieren, sodass evtl. keine Nachrichten von der Dachstation empfangen werden, werden die Zeitpunkte des Drückens gespeichert und überprüft, ob der Button X ms gedrückt wurde
  if (button.status == 1 && (regenpausenAenderungsTimer + dauerRegenpausenAenderungsTimer) > millis() && button.zuvorGedrueckt == 0 && regenpause != 0) {
    button.timer = millis();
    button.zuvorGedrueckt = 1;
  } else if (button.timer + drueckDauerPausenAendrerung < millis() && button.zuvorGedrueckt == 1) {
    button.zuvorGedrueckt = 0;
    button.status = 0;

    Serial.println("---------- BUTTON MIN. 3 SEK GEDRÜCKT! ----------");

    if (regenpause != 3) {  // Nur wenn gerade eine Pause ist, soll der Modus geändert werden können
      regenpause = false;
      Serial.println("Pause zu Schoenwetterpause geändert!");
      digitalWrite(LED_Regenpause, LOW);
      digitalWrite(LED_KeineRegenpause, HIGH);

      LCD_PrintOben("Keine Regenpause");
      regenpause = 3;  // 3 steht für Schoenwetterpause
    } else {
      if (wetterdaten.temperaturFloat <= schwelleKaeltepause) {
        Serial.println("Pause zu Kaeltepause geändert!");
        digitalWrite(LED_Regenpause, HIGH);
        digitalWrite(LED_KeineRegenpause, LOW);

        LCD_PrintOben("Kaeltepause!");
        regenpause = 2;  // 2 steht für Kältepause
      } else {
        Serial.println("Pause zu Regenpause geändert!");
        digitalWrite(LED_Regenpause, HIGH);
        digitalWrite(LED_KeineRegenpause, LOW);

        LCD_PrintOben("Regenpause!");
        regenpause = 1;  // 1 steht für Regenpause
      }
    }
    LCD_PrintUnten("Temp: " + wetterdaten.temperaturString + " Grad");

    // Damit die Anzeigestation den geänderten Pausenmodus anzeigt, müssen die Daten erneut gesendet werden.
    // Die Uhrzeit muss aber aktuell sein, dass die Anzeigstation sie richtig anzeigt. Dafür wird so getan, als ob die LoRa-Daten zu diesem Zeitpunkt empfangen wurden.
    updateUTCTimeVariables();
    loRaData.datumUTCWetterEmpfagen = zeit.DatumUTC;
    loRaData.uhrzeitUTCWetterEmpfagen = zeit.UhrzeitUTC;
    datenAnAnzeigeGesendet = false;
  } else if (button.status == 0 && button.zuvorGedrueckt == 1) {
    button.zuvorGedrueckt = 0;
  }

  // Falls noch nicht geschehen, sollen die neuesten Wetterdaten an die Anzeigestation gesendet werden:
  if (datenAnAnzeigeGesendet == false && httpAnfrageLaeuft == false && (timerAblaufzeitHttpAnfrage + ablaufzeitHttpAnfrage) < millis() && WLAN_STATUS == 0) {
    String wetterdatenFuerAnzeige = serverName
                                    + "datum=" + loRaData.datumUTCWetterEmpfagen + "&"
                                    + "uhrzeit=" + loRaData.uhrzeitUTCWetterEmpfagen + "&"
                                    + "temperatur=" + wetterdaten.temperaturString + "&"
                                    + "luftfeuchtigkeit=" + wetterdaten.luftfeuchtigkeitString + "&"
                                    + "pausenstatus=" + regenpause + "&"
                                    + "regentropfen=" + wetterdaten.regenstaerke;

    Serial.println(wetterdatenFuerAnzeige);

    httpAnfrageLaeuft = true;
    timerAblaufzeitHttpAnfrage = millis();

    http.initialize(wetterdatenFuerAnzeige);
    http.makeRequest(
      []() {  // onSuccess Callback
        Serial.println("Request erfolgreich!");
        Serial.println("HTTP Status Code: " + String(http.getStatusCode()));
        Serial.println("Antwort: " + http.getBody());

        if (http.getBody() == bestaetigungAnzeigestation) {
          datenAnAnzeigeGesendet = true;
        }

        httpAnfrageLaeuft = false;
      },
      [](String msg) {  // onFail Callback
        Serial.println("Fehler: " + msg);

        httpAnfrageLaeuft = false;
        WiFi.disconnect();  // WLAN trennen, sodass es neu verbunden werden kann. Dann wird die Anfrage automatisch erneut versucht und funktioniert damit vielleicht wieder.
      });
  }

  if ((timerAblaufzeitHttpAnfrage + ablaufzeitHttpAnfrage) < millis() && httpAnfrageLaeuft == true) {
    Serial.println("HTTP-Request Timeout, Verbindung wird zurückgesetzt.");
    httpAnfrageLaeuft = false;
  }


  int packetSize = LoRa.parsePacket();
  if (packetSize) {
    // Wenn ein LoRa-Paket empfangen wurde...
    Serial.println("LoRa-Daten empfangen: ");
    while (LoRa.available()) {
      loRaData.empfangenesPaket = LoRa.readString();  // Paket abspeichern
      Serial.print(loRaData.empfangenesPaket);        // und ausgeben
    }
    Serial.println("    Empfangsqualität:    RSSI: " + String(LoRa.packetRssi()) + " dBm    |    SNR: " + String(LoRa.packetSnr()) + " dB\n");  // Signalqualität ausgeben

    if (loRaData.empfangenesPaket.startsWith(loRaData.praefix + loRaData.typTemp + loRaData.seperator1) && loRaData.empfangenesPaket.indexOf(loRaData.seperator2) != -1 && loRaData.empfangenesPaket.indexOf(loRaData.seperator3) != -1 && loRaData.empfangenesPaket.indexOf(loRaData.seperator4) != -1) {
      // Normales Paket von Dachstation empfangen mit Temperatur und Luftfeuchtigkeit (keine Regenmessung)
      Serial.println("LoRaData starts with " + loRaData.praefix + loRaData.typTemp);
      verarbeiteLoRaWetterdaten();
      Serial.println("Temperatur: " + wetterdaten.temperaturString + "   Luftfeuchtigkeit: " + wetterdaten.luftfeuchtigkeitString + "\n");

      // Während auf dem Display Regenpause/ Schoenwetterpause angezeigt wird, soll nur die Temperatur im unteren Displaybereich angezeigt werden.
      // Solange die Pausen-LEDs noch leuchten, soll auf dem Display auch der Pausenstatus angezeigt bleiben.
      if (millis() < (timerPausenLEDsAus + dauerLEDsAnNachRegenmessung)) {
        LCD_PrintUnten("Temp: " + wetterdaten.temperaturString + " Grad");
      } else {
        LCD_PrintOben("Temp: " + wetterdaten.temperaturString + " Grad");
        LCD_PrintUnten("LF: " + wetterdaten.luftfeuchtigkeitString + "%");
      }
    } else if (loRaData.empfangenesPaket.startsWith(loRaData.praefix + loRaData.typRain + loRaData.seperator1) && loRaData.empfangenesPaket.indexOf(loRaData.seperator2) != -1 && loRaData.empfangenesPaket.indexOf(loRaData.seperator3) != -1 && loRaData.empfangenesPaket.indexOf(loRaData.seperator4) != -1) {
      // Paket von der Dachstation enthält ein Ergebnis der Regenmessung
      Serial.println("LoRaData starts with " + loRaData.praefix + loRaData.typRain);
      verarbeiteLoRaWetterdaten();
      wetterdaten.regenstaerke = loRaData.empfangenesPaket.substring(loRaData.empfangenesPaket.indexOf(loRaData.seperator4) + 1).toInt();
      Serial.println("Regenstärke:" + String(wetterdaten.regenstaerke) + "   Temperatur: " + wetterdaten.temperaturString + "   Luftfeuchtigkeit: " + wetterdaten.luftfeuchtigkeitString + "\n");

      // Lege Pausenstatus anhand der Wetterdaten fest:
      if (wetterdaten.temperaturFloat <= schwelleKaeltepause) {  // Wenn die Temperatur kleiner/ gleich ist, als/ wie die Schwelle, dann ist eine Kältepause
        digitalWrite(LED_Regenpause, HIGH);
        digitalWrite(LED_KeineRegenpause, LOW);

        LCD_PrintOben("Kaeltepause!");
        regenpause = 2;                                  // 2 steht für Kältepause
      } else {                                           // Wenn keine Kältepause ist, dann...
        if (wetterdaten.regenstaerke > regenschwelle) {  //... ist entweder eine Regenpause ...
          digitalWrite(LED_Regenpause, HIGH);
          digitalWrite(LED_KeineRegenpause, LOW);

          LCD_PrintOben("Regenpause!");
          regenpause = 1;
        } else {  // oder eine Schönwetterpause/ keine Regenpause
          digitalWrite(LED_Regenpause, LOW);
          digitalWrite(LED_KeineRegenpause, HIGH);

          LCD_PrintOben("Keine Regenpause");
          regenpause = 3;
        }
      }

      LCD_PrintUnten("Temp: " + wetterdaten.temperaturString + " Grad");
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

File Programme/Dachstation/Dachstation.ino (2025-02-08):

/*
Regenpausenanzeiger - Dachstation.ino
Copyright (C) 2025  Aurelio Dobmeier

Dieses Programm ist freie Software: Sie können es unter den Bedingungen
der GNU Affero General Public License, wie von der Free Software Foundation,
Version 3 der Lizenz oder (nach Ihrer Wahl) jeder späteren
veröffentlichten Version, weitergeben und/oder modifizieren.

Dieses Programm wird in der Hoffnung verteilt, dass es nützlich sein wird,
aber OHNE JEDE GEWÄHRLEISTUNG; auch ohne die implizite Gewährleistung der
MARKTGÄNGIGKEIT oder der EIGNUNG FÜR EINEN BESTIMMTEN ZWECK.
Weitere Einzelheiten finden Sie in der GNU Affero General Public License.

Sie sollten eine Kopie der GNU Affero General Public License zusammen mit
diesem Programm erhalten haben. Wenn nicht, siehe <https://www.gnu.org/licenses/>.

----

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
You should have received a copy of the GNU Affero General Public License
along with this program.  If not, see <https://www.gnu.org/licenses/>.
*/


//==================== Bibliotheken ====================
// Die Bibliotheken müssen eventuell nachinstalliert werden!
//---------- LoRa ----------
#include <LoRa.h>
#include <SPI.h>

//---------- Temperatur- und Luftfeuchtigkeitssensor (DHT22) ----------
#include "DHT.h"
//++++++++++++++++++++ Bibliotheken ++++++++++++++++++++


//==================== LoRa ====================
#define SS 5
#define RST 14
#define DIO0 2

// Einstellen der genauen Freuqenz. Ist abhängig von der Region und muss den entsprechenden Vorgaben eingestellt werden!!!
#define BAND 869.525E6  // Bsp. Frequenz in Hz für 869,525 MHz

String LoRaData;                     //In dieser Variable werden empfangene Daten gespeichert
bool sendeTempOderRegenstaerke = 0;  //Temperaturmesseung = 0; Regenmessung = 1; Variable wird beim Einschalten des Geräts auf Temp (0) gesetzt.
                                     //Beim Empfang von Regenmessung wird sie auf 1 gesetzt.

// Genauere Erklärungen zu diesen Variablen befinden sich im Programm der Sekretariatsstation!
// DIE EINSTELLUNGEN DER VARIABLEN MUSS MIT DENEN DER SEKRETARIATSSTATION ÜBEREINSTIMMEN!
struct LoRaData {
  const String praefix = "#RPA";
  const String typTemp = "temp";
  const String typRain = "rain";
  const String seperator1 = "B";
  const String seperator2 = "T";
  const String seperator3 = "H";
  const String seperator4 = "W";
  const String typSleep = "sleep";
  const String seperatorSleep = "S";
  const String seperatorDauerRmessung = "D";

  String empfangenesPaket = "";
} loRaData;
//++++++++++++++++++++ LoRa ++++++++++++++++++++


//==================== Temperatur- und Luftfeuchtigkeitssensor (DHT22) ====================
#define DHTPIN 27          //Pin 27 am ESP32
#define DHTTYPE DHT22      //Type: DHT 22 (Es gibt verschiedene Varianten des Sensors)
DHT dht(DHTPIN, DHTTYPE);  // Initialize DHT sensor.

float temperatur;    //Variable, um Temperatur zu speichern. (float kann Kommazahlen enthalten)
float feuchtigkeit;  //Variable, um Luftfeuchtigkeit zu speichern.
//++++++++++++++++++++ Temperatur- und Luftfeuchtigkeitssensor (DHT22) ++++++++++++++++++++


//==================== Regensensor ====================
#define Regensensor 34
unsigned long tropfenzaehler = 0;
int schwelle = 2;  // Schwelle für den Regensensor: Legt fest, ab wann der Messwert am Pin als Regentropfen erkannt wird.
//++++++++++++++++++++ Regensensor ++++++++++++++++++++


//==================== Sonstiges ====================
#define StromPin 25  // Pin, der den Transistor ansteuert, mit dem der DHT 22, das LoRa-Modul und der Regensensor, sowie Spannunsgsteiler für Spannungsmessung des Akkus mit Strom versorgt werden.

// Pin, an dem man einen Buzzer anschließen kann, der immer kurz piept, wenn Tropfen gezählt (für Test- oder Demonstrationszwecke)
#define Buzzer 13  // Wird auf HIGH gesetzt, wenn ein Tropfen erkannt wurde

// An Pin 26 kann ein Spannungsteiler angeschlossen werden, um die Spannung des Akkus zu ermitteln.
// Diese Methode ist allerdings nicht sehr genau und dient nur der groben Überwachung.
#define BatSpannungsPin 26
const float r1 = 100000.0;    // Wert von R1 in Ohm (100 kΩ)
const float r2 = 300000.0;    // Wert von R2 in Ohm (300 kΩ)
const float vRef = 3.3;       // Referenzspannung des ADC
const float ausgleich = 0.0;  // Ausgleichswert
float battSpannung = 0;
const byte anzahlSpannungsMessungen = 20;  // Um Genauigkeit zu erhöhen werden mehrere Messungen hintereinander durchgeführt

// Schaltung Spannungsteiler:
//        Akku (+) ----- R1 -----+----- ADC Pin (BatSpannungsPin: 26)
//                               |
//                               R2
//                               |
//  GND (Emitter Transistor) ----+
//++++++++++++++++++++ Sonstiges ++++++++++++++++++++


//==================== Variablen, die dafür sorgen, dass nicht empfange Pakete nochmals gesendet werden ====================
int anzahlFehlSendeversuche = 0;                      // Nach einer bestimmten Anzahl an gesendeten Paketen, die nicht von der Station im Sekretariat empfangen wurden schaltet sich die Station in Sleep-Modus für 10 min.
const int anzahlSendeversuche = 3;                    // Legt fest, wie oft die Daten an das Sekretariat gesendet werden, wenn es nicht antwortet und nur Temp und Hum gesendet werden.
const int zusaetzlicheSendeversucheRegenmessung = 3;  // Wird zu AnzahlSendeversuche addiert, wenn das Ergebis einer Regenmessung gesendet wird, sodass es auf jeden Fall ankommt.
const int intervallSendeversuche = 5000;              // Intervall der erneuten Sendeversuche (je länger, desto mehr Stromverbrauch, da der ESP32 währenddessen nicht im DeepSleep ist)
const int dauerSleepNachErfolglosemSenden = 600000;   // Schlafenszeit nach erfolglosem Senden (-> wenn die Sekretariatsstation nicht auf das Paket geantwortet hat)
long timer = 0;                                       // Timer, dass Daten immer wieder im Intervall (von intervallSendeversuche) gesendet werden, wenn keine Antwort von Sekretariatsstation erfolgte
//++++++++++++++++++++ Variablen, die dafür sorgen, dass nicht empfange Pakete nochmals gesendet werden ++++++++++++++++++++


// Funktion, die aufgerufen wird, um den DeepSleep-Modus zu starten:
void deepSleep(int sleepTime) {
  Serial.println("Vorbereitung für Deep Sleep...");
  digitalWrite(StromPin, LOW);  // Um Energie zu sparen wird der Strom der Sensoren und Aktoren am Transistor ausgeschaltet

  // Vorbereiten der Dauer des Deep-Sleeps in Mikrosekunden
  esp_sleep_enable_timer_wakeup(sleepTime * 1000);  //Die sleepTime wird vom Server in Millisekunden geschickt und muss in Mikrosekunden umgerechnet werden.

  Serial.println("ESP32 geht in den Deep Sleep-Modus...");

  Serial.flush();          //Warten, bis alles an den Computer gesendet wurde
  esp_deep_sleep_start();  //Starten des Tiefschlafs
}
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

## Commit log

2025-02-08 Arduino-Sketche für Sekretariats- und Dachstation
2025-02-16 Anleitung für die Einrichtung der Anzeigestation
